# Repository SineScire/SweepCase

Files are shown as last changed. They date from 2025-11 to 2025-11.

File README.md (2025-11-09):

<a href="https://github.com/SineScire/SweepCase">SweepCase</a> © 2025 by <a href="https://github.com/SineScire">SineNomen</a> is licensed under <a href="https://creativecommons.org/licenses/by-nc-sa/4.0/">CC BY-NC-SA 4.0</a>

# SweepCase
A 3D printed MagSafe compatible case for the [sweep](https://github.com/davidphilipbarr/Sweep), designed to be compatible with the [Sweep2.x](https://github.com/davidphilipbarr/Sweep/tree/main/Sweep%20v2.2) and [Sweep Bling LP](https://github.com/davidphilipbarr/Sweep/tree/main/Sweep%20Bling%20LP) versions.

Check out the manual [here](https://github.com/SineScire/SweepCase/blob/main/Manual.md).

There are two versions of this case, one where there is an opening for the TRRS port and one without. Both versions have access to an on/off switch.
| Wired | Wireless |
| --- | ----- |
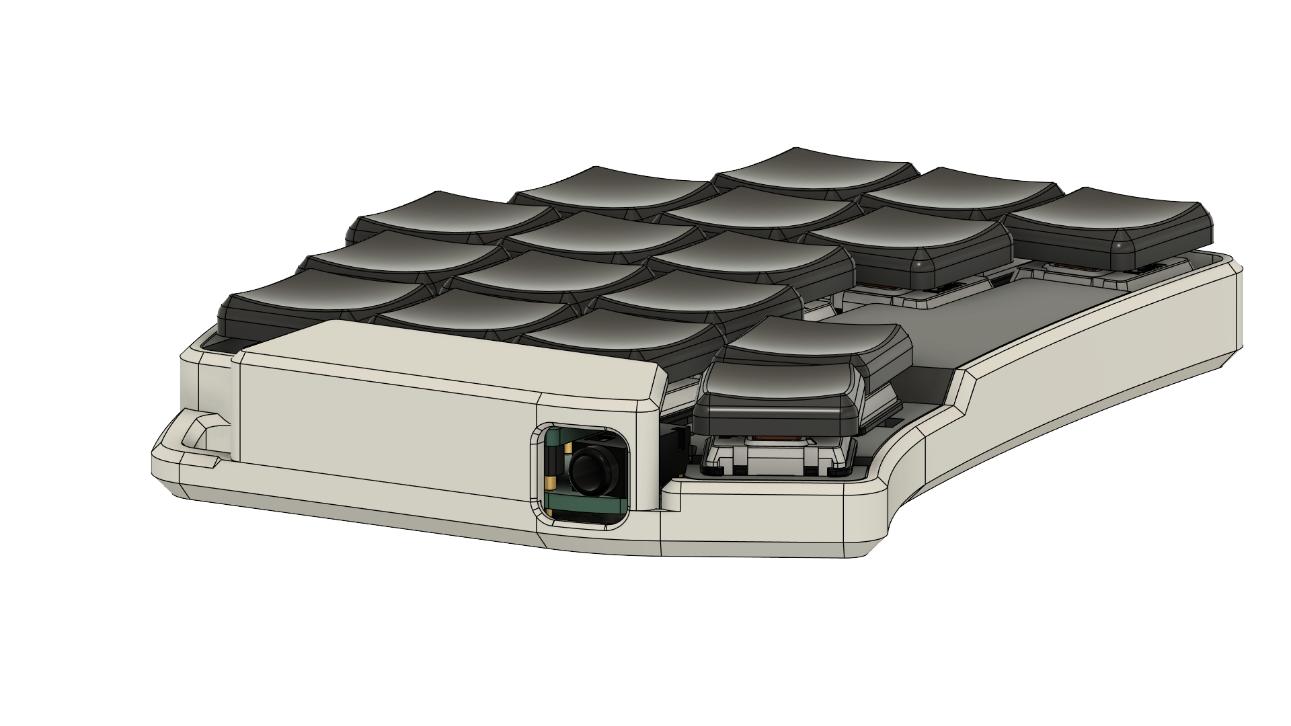
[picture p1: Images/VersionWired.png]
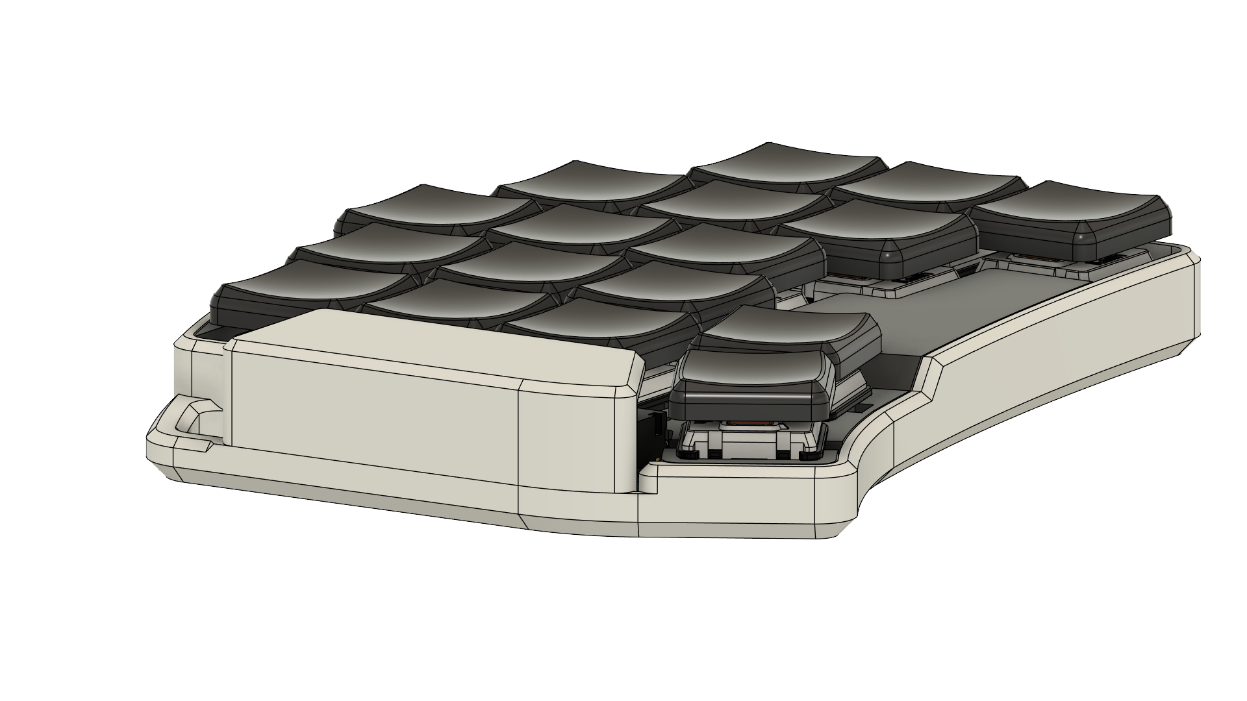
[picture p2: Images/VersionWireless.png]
|  | 

| Case |
| ---- |
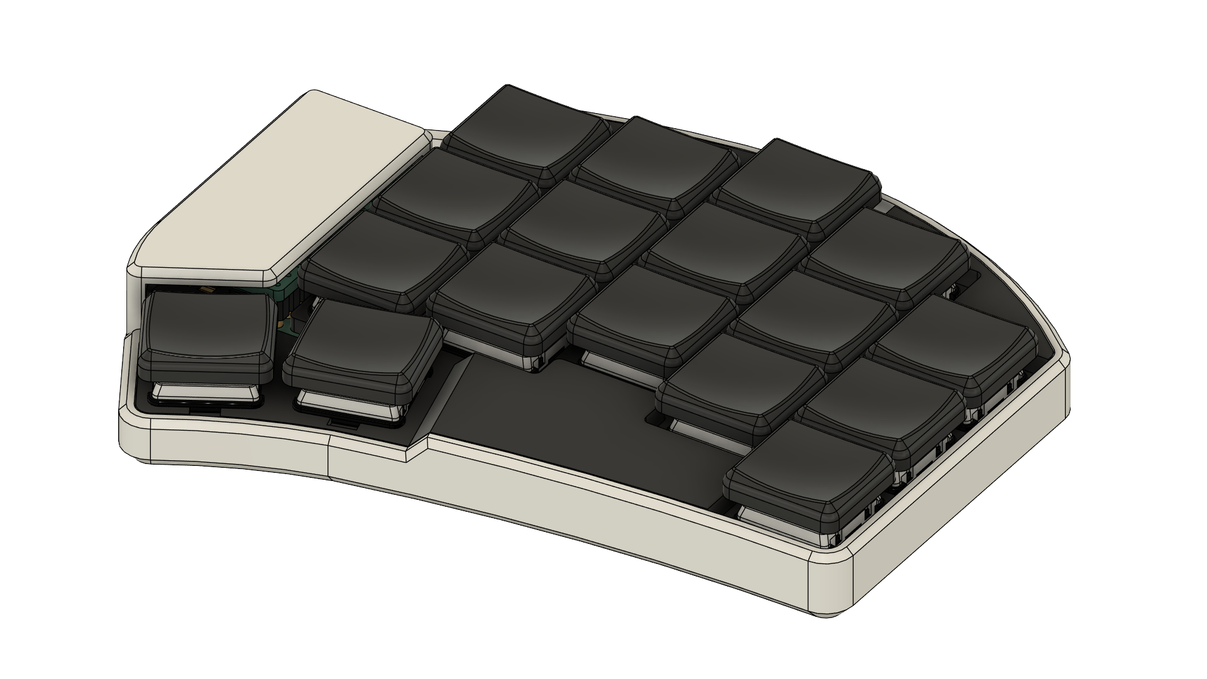
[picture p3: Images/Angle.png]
|  |

## Credits
* [The people](https://github.com/davidphilipbarr/Sweep/tree/main/Sweep%20v2.2) that developed the sweep
* [Keycapsss](https://keycapsss.com/) for providing the PCB and materials

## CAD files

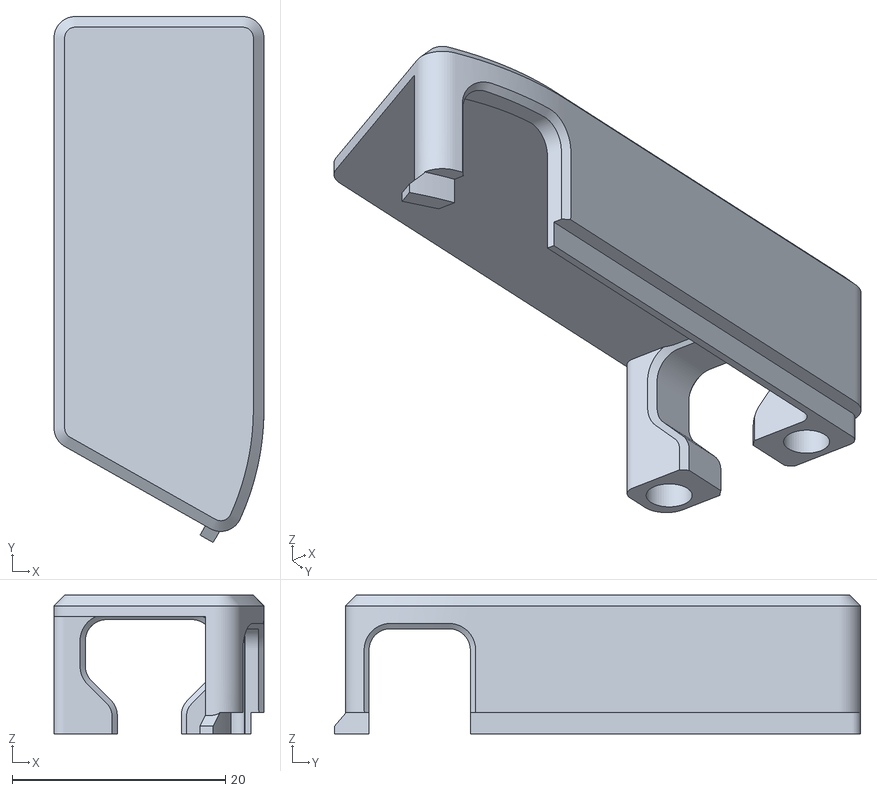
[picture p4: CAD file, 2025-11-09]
Files/Wired/MCU Left Wired.stl
19.7 x 49.4 x 13.0

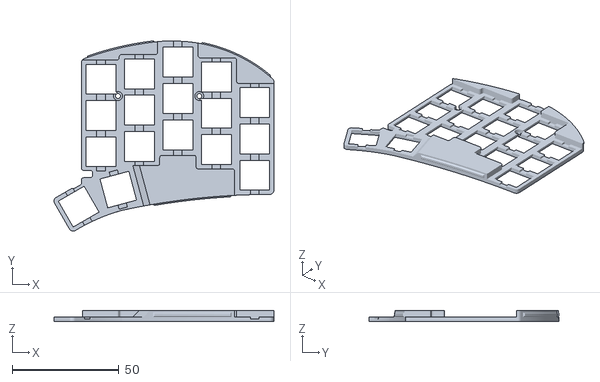
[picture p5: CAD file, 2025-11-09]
Files/Wireless/Top Plate Right.stl
103.1 x 89.2 x 5.20

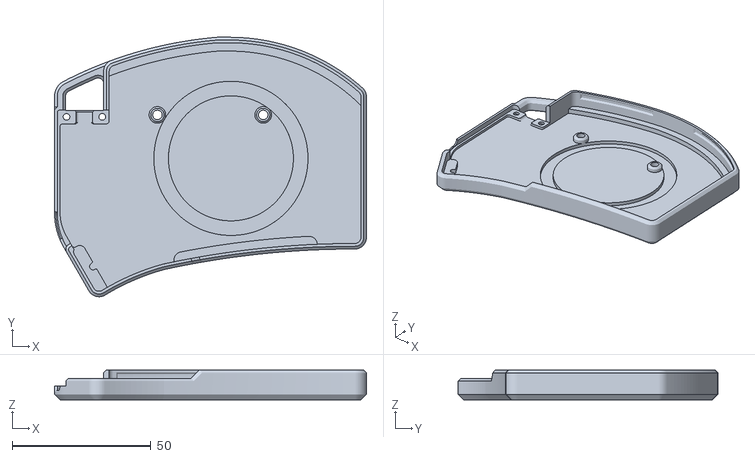
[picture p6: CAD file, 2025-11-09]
Files/Wired/Bottom Housing Right Wired.stl
112.4 x 93.5 x 10.8

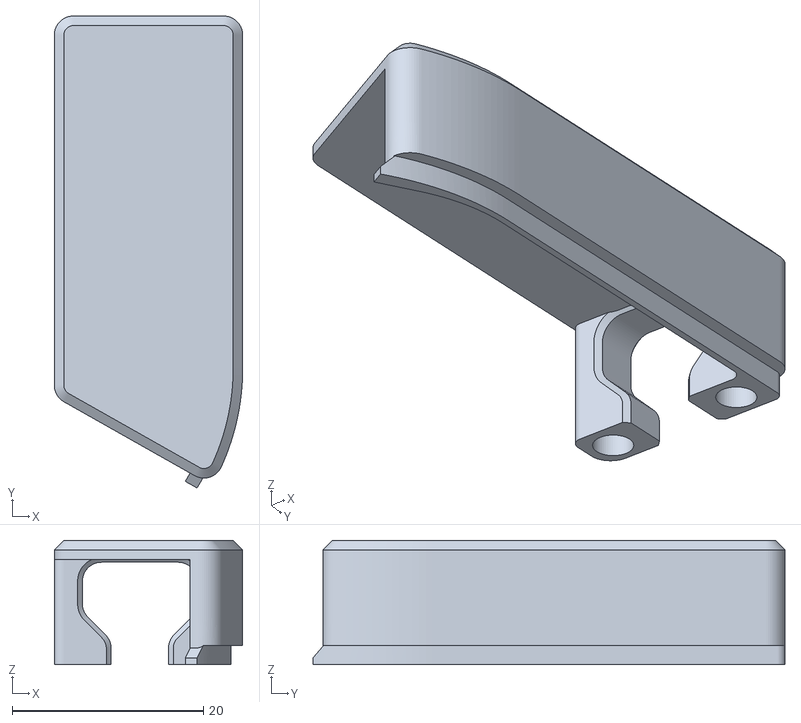
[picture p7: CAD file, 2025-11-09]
Files/Wireless/MCU Left Wireless.stl
19.7 x 49.4 x 13.0

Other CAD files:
Files/Wireless/Top Plate Left.stl
Files/Wired/Top Plate Left.stl
Files/Wired/Bottom Housing Left Wired.stl
Files/Wireless/Bottom Housing Right Wireless.stl
Files/Wireless/MCU Right Wireless.stl
Files/Wired/MCU Right Wired.stl
Files/Wireless/Bottom Housing Left Wireless.stl

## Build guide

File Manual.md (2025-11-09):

## BOM

* For a complete set of two cases.

| Part | Quantity | Description |
| ---- | --- | --- |
| Plate | 2x | 3D printed mirrored part |
| Bottom Housing | 2x | 3D printed mirrored part |
| MCU Cover | 2x | 3D printed mirrored part |
| Threaded Inserts | 8x | m2x3mm or smaller brass heat inserts |
| Screws | 8x | m2x5 screws |
| Rubber Feet | 8x | 2mm thick rubber feet with a diameter of 15mm |
| MagSafe Magnets | 2x | Optional 1mm thick circular magnet array for MagSafe mounting |
| Soldering Iron | 1x | To insert the threaded inserts |

## Printing the parts
* Suggested printing orientation for the parts
* Supports are enabled
* To print the right half the part must be mirrored in the slicing software

| Plate | Bottom housing | MCU Cover |
| ----- | --- | --- |
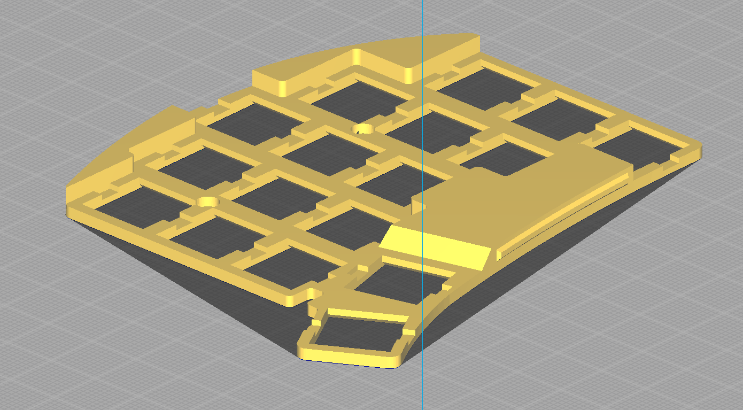
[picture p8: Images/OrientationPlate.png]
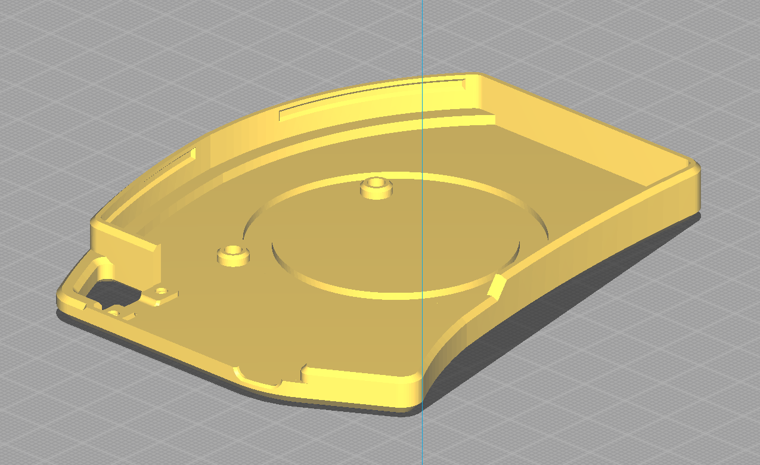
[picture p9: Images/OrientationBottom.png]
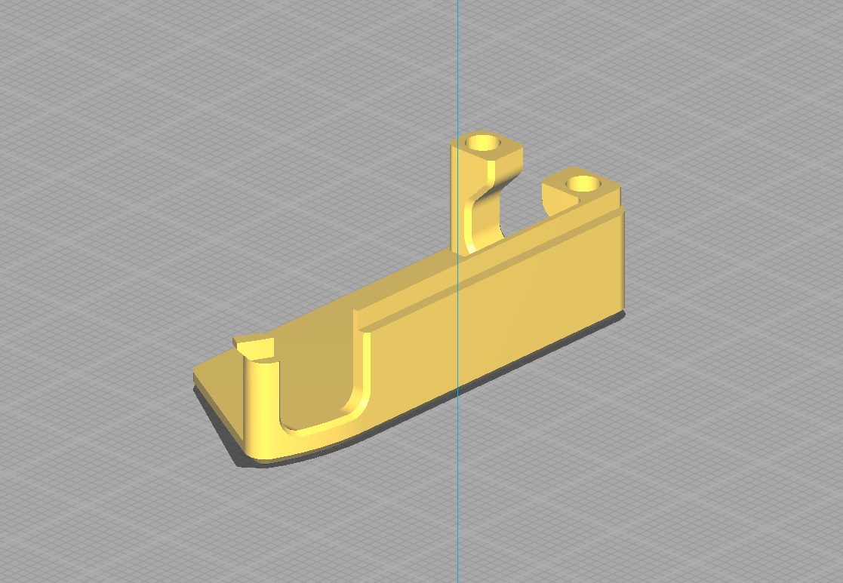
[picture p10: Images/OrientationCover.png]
|  |  |  |

## Assembling the case

Use a soldering iron to insert the threaded inserts in the bottom housings and the MCU covers in the blue highlighted holes.

| Bottom housing | MCU Cover |
| --- | --- |
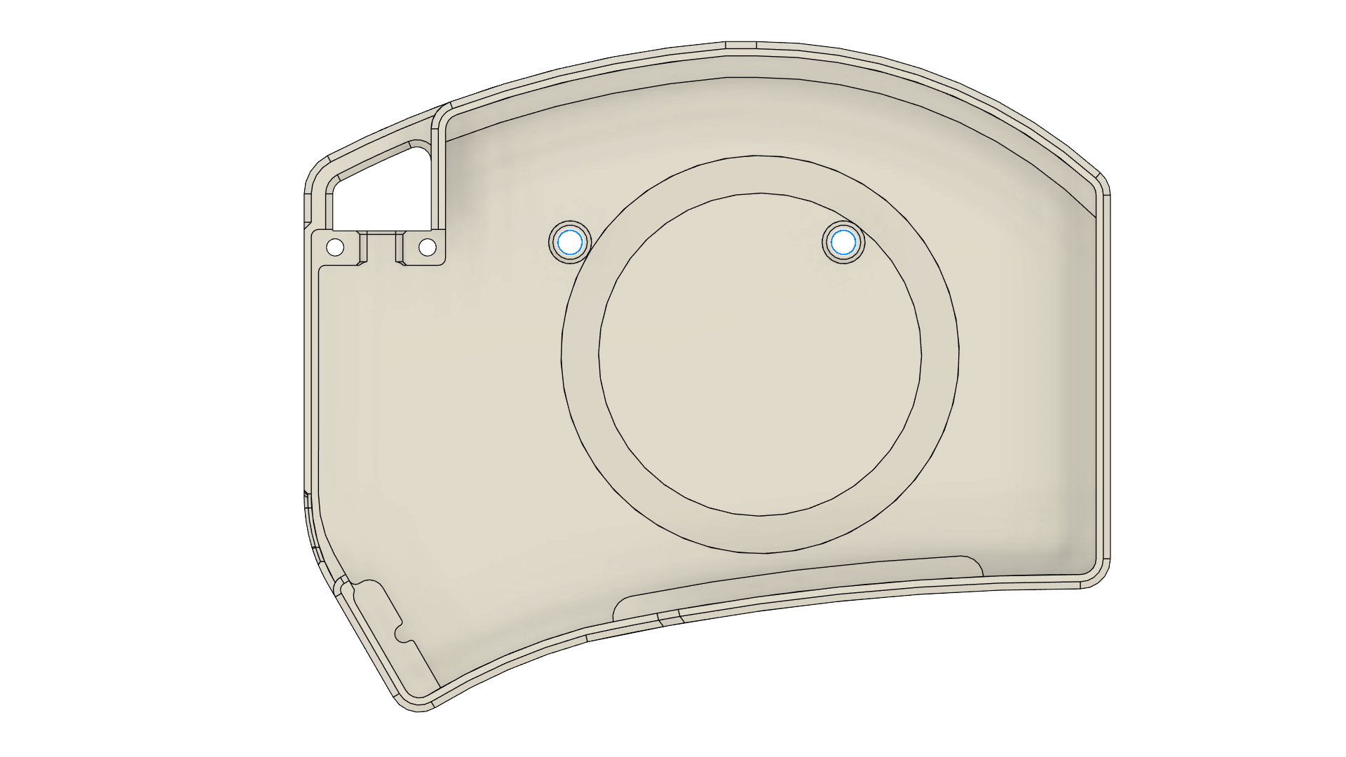
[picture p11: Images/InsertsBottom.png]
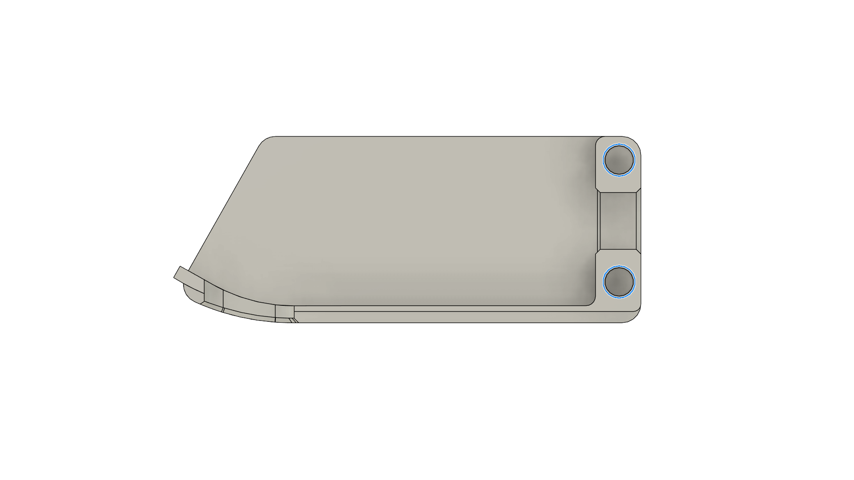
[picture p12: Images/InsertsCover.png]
|  |  |

Place the optional MagSafe ring inside the case

| Placing the MagSafe ring |
| ------------------------ |
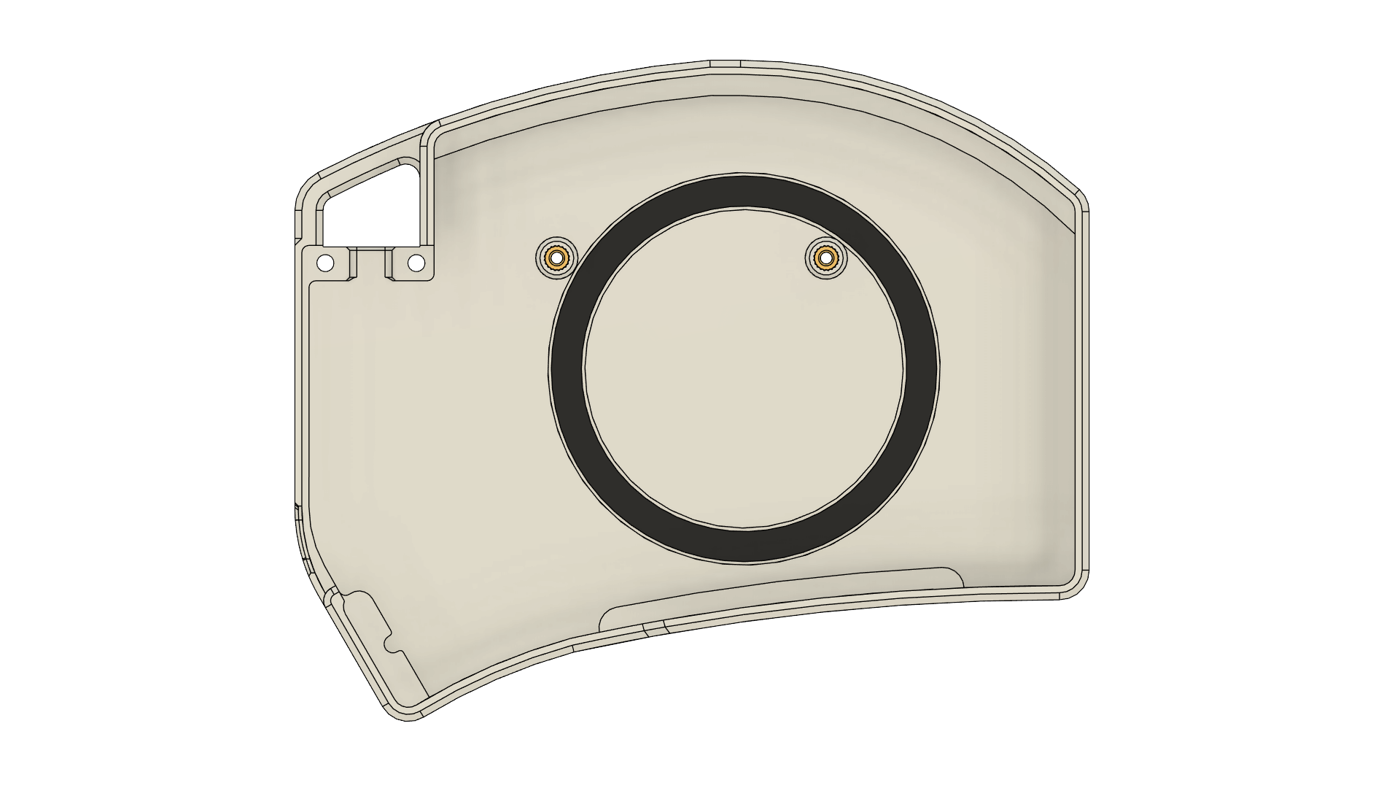
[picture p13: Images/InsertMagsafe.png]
|  |

Assemble the case further by placing the PCB in the bottom housing and snap-fitting the plate in place. The plate can be fastened with two screws to the bottom housing

| Placing the PCB and fastening the plate |
| --------------------------------------- |
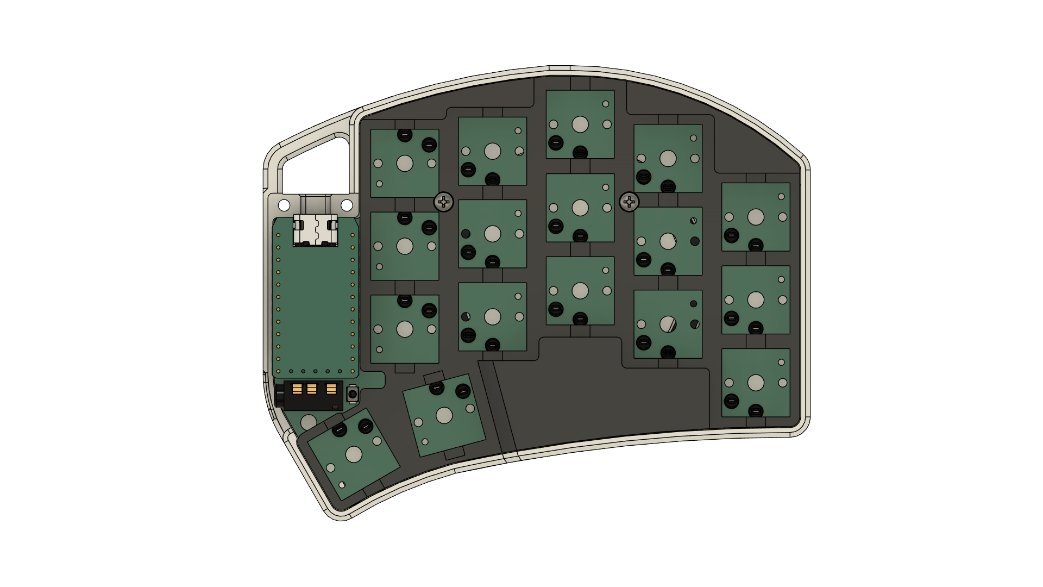
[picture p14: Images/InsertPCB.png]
|  |

Finally the MCU cover can be placed on the case. Make sure to insert the blue highlighted back corner first into the case, the cover can be fastened with two screws. Finish the case off by placing the rubber feet on the bottom of the case.

| Placing the cover |
| ----------------- |
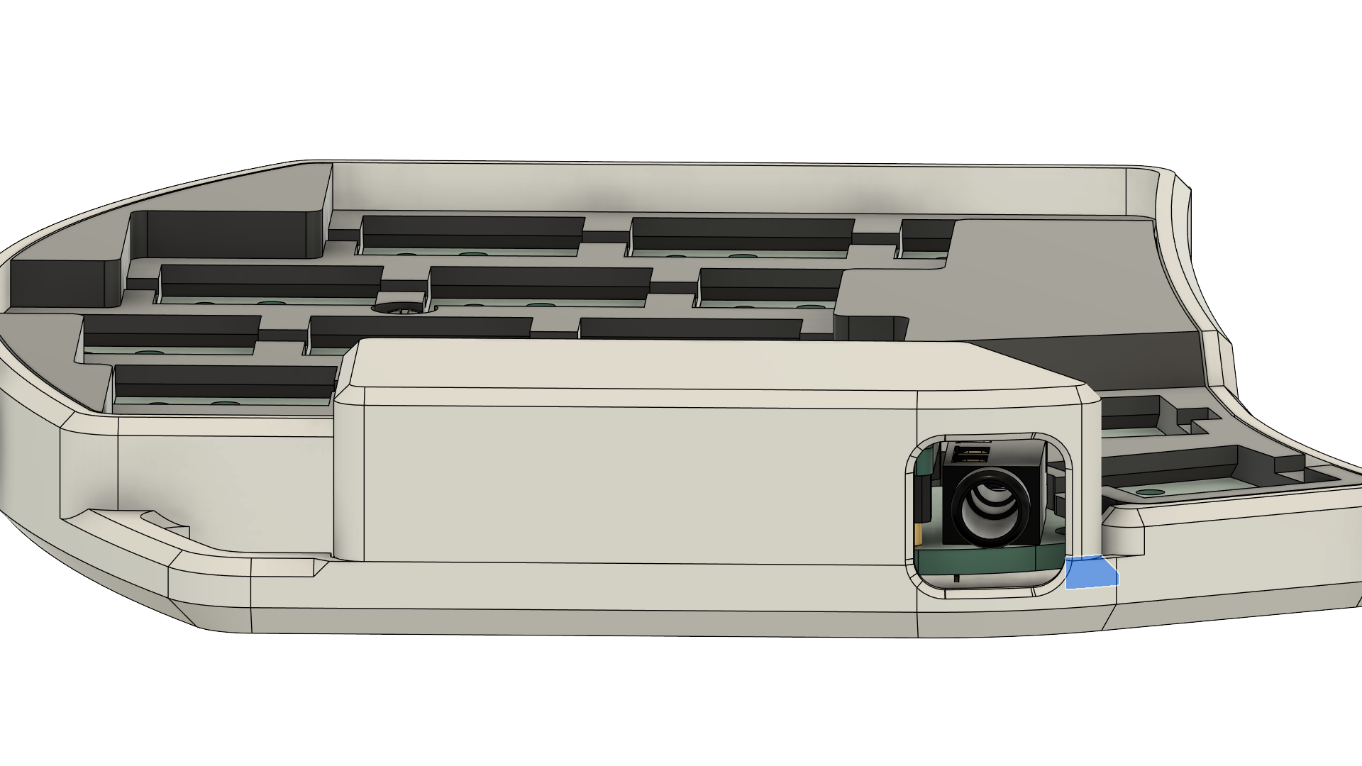
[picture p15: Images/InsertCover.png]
|  |

The keyboard can now be completed with your switches and keycaps of choice. Enjoy the case!

| Completed case |
| -------------- |
|  |
